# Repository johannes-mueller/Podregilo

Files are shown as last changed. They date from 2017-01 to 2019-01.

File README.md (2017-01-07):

# Podregilo

Arduino based hardware to control a podcasting DAW.

## Disclaimer

By now this project is far from being useful. It might be interesting to other developers though.

# Goal

We are developing and constructing an Arduino based hardware box to control our
DAW while podcasting. The following features are planned:

* mute buttons for all speakers

* buttons to start, stop and prepare the recording

* LED indications of the meter levels of the voices

* buttons to start jingles and other clips

* displaying the current time

# Status

## Prototypes

* First prototype on strip board

  The first prototype was soldered and wired completely manually on stripboards
  using magnet wire for every single comnnection. It was quite a tedious work
  building it but it has the advantage that we could test and develop it
  actually while building the first prototype. In the end the prototype worked
  but turned out to be far to unstable for serious work.

* Second prototype on an etched PCB.

  With what we've learned from the first prototype design, we designed the
  circuit in KiCad and then designed two PCBs, one for the front panel and one
  for the actual circuit. These PCBs we had produced by a professional PCB
  manufacturer. It turned out that we had some bugs in the circuit design which
  we for the second prototype fixed using a grinding tool and again a bit of
  magnet wire.

## Current Status

Right now we have the second prototype up and running and plan to use it in
actual everyday podcasting for a couple of months. Depending on our experiences
we will either have new PCBs produced or we will add some features, that need
hardware modifications.

# Used technology

The hardware is build around an Arduino compatible board, probably the Arduino
nano. We are using parallel shift registers SN74HC165 and SN74HC595 to get and
set the states of our hardware items. On the software side we speak OSC to our
DAW and also probably MIDI to other software. The meter levels we get via
jack. The software is written in python.

# Aimed platform

We are developing on Linux/Ardour. It shouldn't be too difficult to port the
stuff to Mac/Ardour or even Mac/Reaper.

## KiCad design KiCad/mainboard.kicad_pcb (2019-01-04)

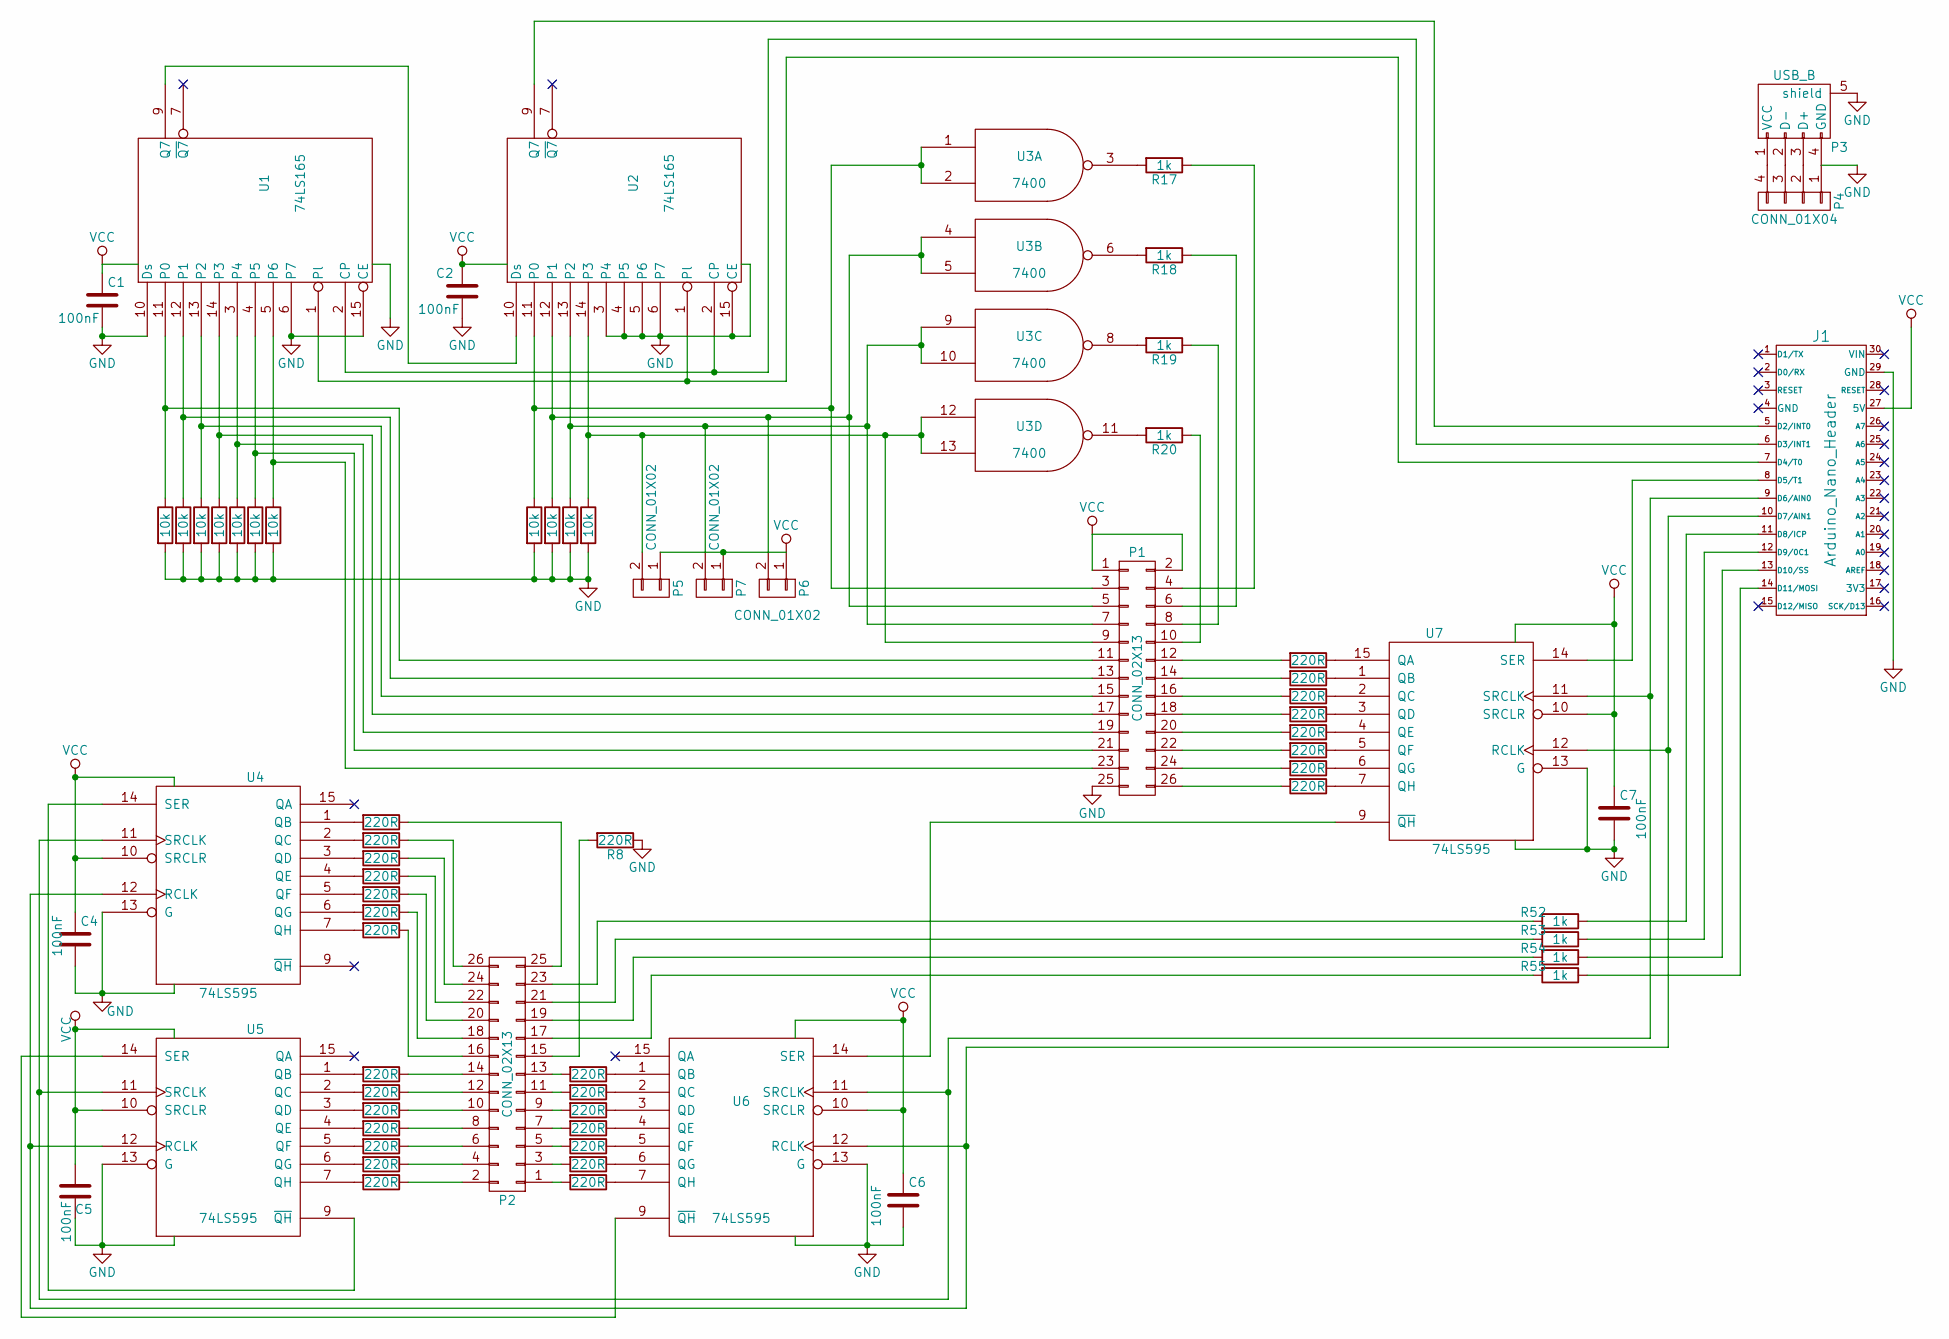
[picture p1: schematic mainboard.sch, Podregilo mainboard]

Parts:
C1, C2, C4, C5, C6, C7: 100nF; C_Disc_D3_P2.5
J1: Arduino_Nano_Header; arduino_nano_header
P1, P2: CONN_02X13; Pin_Header_Straight_2x13
P3: USB_B
P4: CONN_01X04; Pin_Header_Straight_1x04
P5, P6, P7: CONN_01X02; Pin_Header_Straight_1x02
R1, R2, R3, R4, R5, R6, R7, R13, R14, R15, R16: 10k; Resistor_Horizontal_RM7mm
R8, R21, R22, R23, R24, R25, R26, R27, R29, R30, R31, R32, R33, R34, R35, R37, R38, R39, R40, R41, R42, R43, R44, R45, R46, R47, R48, R49, R50, R51: 220R; Resistor_Horizontal_RM7mm
R17, R18, R19, R20, R52, R53, R54, R55: 1k; Resistor_Horizontal_RM7mm
U1, U2: 74LS165; DIP-16_W7.62mm
U3: 7400; DIP-14_W7.62mm
U4, U5, U6, U7: 74LS595; DIP-16_W7.62mm

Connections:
GND: C1.2, C2.2, C4.2, C5.1, C6.2, C7.2, J1.29 (GND), P1.25, P3.4 (GND), P3.5 (shield), P4.1, R1.2, R2.2, R3.2, R4.2, R5.2, R6.2, R7.2, R8.1, R13.2, R14.2, R15.2, R16.2, U1.6 (P7), U1.8 (GND), U1.10 (Ds), U1.15 (CE), U2.3 (P4), U2.4 (P5), U2.5 (P6), U2.6 (P7), U2.8 (GND), U2.15 (CE), U3.7 (GND), U4.8 (GND), U4.13 (G), U5.8 (GND), U5.13 (G), U6.8 (GND), U6.13 (G), U7.8 (GND), U7.13 (G)
unnamed: J1.5 (D2/INT0), U2.9 (Q7)
unnamed: J1.6 (D3/INT1), U1.2 (CP), U2.2 (CP)
unnamed: J1.7 (D4/T0), U1.1 (Pl), U2.1 (Pl)
unnamed: J1.8 (D5/T1), U7.14 (SER)
unnamed: J1.9 (D6/AIN0), U4.11 (SRCLK), U5.11 (SRCLK), U6.11 (SRCLK), U7.11 (SRCLK)
unnamed: J1.10 (D7/AIN1), U4.12 (RCLK), U5.12 (RCLK), U6.12 (RCLK), U7.12 (RCLK)
unnamed: J1.11 (D8/ICP), R52.1
unnamed: J1.12 (D9/0C1), R53.1
unnamed: J1.13 (D10/SS), R54.1
unnamed: J1.14 (D11/MOSI), R55.1
unnamed: P1.3, R13.1, U2.11 (P0), U3.1, U3.2
unnamed: P1.4, R17.1
unnamed: P1.5, P6.2, R14.1, U2.12 (P1), U3.4, U3.5
unnamed: P1.6, R18.1
unnamed: P1.7, P7.2, R15.1, U2.13 (P2), U3.9, U3.10
unnamed: P1.8, R19.1
unnamed: P1.9, P5.2, R16.1, U2.14 (P3), U3.12, U3.13
unnamed: P1.10, R20.1
unnamed: P1.11, R1.1, U1.11 (P0)
unnamed: P1.12, R44.2
unnamed: P1.13, R2.1, U1.12 (P1)
unnamed: P1.14, R45.2
unnamed: P1.15, R3.1, U1.13 (P2)
unnamed: P1.16, R46.2
unnamed: P1.17, R4.1, U1.14 (P3)
unnamed: P1.18, R47.2
unnamed: P1.19, R5.1, U1.3 (P4)
unnamed: P1.20, R48.2
unnamed: P1.21, R6.1, U1.4 (P5)
unnamed: P1.22, R49.2
unnamed: P1.23, R7.1, U1.5 (P6)
unnamed: P1.24, R50.2
unnamed: P1.26, R51.2
unnamed: P2.1, R43.2
unnamed: P2.2, R35.1
unnamed: P2.3, R42.2
unnamed: P2.4, R34.1
unnamed: P2.5, R41.2
unnamed: P2.6, R33.1
unnamed: P2.7, R40.2
unnamed: P2.8, R32.1
unnamed: P2.9, R39.2
unnamed: P2.10, R31.1
unnamed: P2.11, R38.2
unnamed: P2.12, R30.1
unnamed: P2.13, R37.2
unnamed: P2.14, R29.1
unnamed: P2.15, R8.2
unnamed: P2.16, R27.1
unnamed: P2.17, R55.2
unnamed: P2.18, R26.1
unnamed: P2.19, R54.2
unnamed: P2.20, R25.1
unnamed: P2.21, R53.2
unnamed: P2.22, R24.1
unnamed: P2.23, R52.2
unnamed: P2.24, R23.1
unnamed: P2.25, R21.1
unnamed: P2.26, R22.1
unnamed: P3.1 (VCC), P4.4
unnamed: P3.2 (D-), P4.3
unnamed: P3.3 (D+), P4.2
unnamed: R17.2, U3.3
unnamed: R18.2, U3.6
unnamed: R19.2, U3.8
unnamed: R20.2, U3.11
unnamed: R21.2, U4.1 (QB)
unnamed: R22.2, U4.2 (QC)
unnamed: R23.2, U4.3 (QD)
unnamed: R24.2, U4.4 (QE)
unnamed: R25.2, U4.5 (QF)
unnamed: R26.2, U4.6 (QG)
unnamed: R27.2, U4.7 (QH)
unnamed: R29.2, U5.1 (QB)
unnamed: R30.2, U5.2 (QC)
unnamed: R31.2, U5.3 (QD)
unnamed: R32.2, U5.4 (QE)
unnamed: R33.2, U5.5 (QF)
unnamed: R34.2, U5.6 (QG)
unnamed: R35.2, U5.7 (QH)
unnamed: R37.1, U6.1 (QB)
unnamed: R38.1, U6.2 (QC)
unnamed: R39.1, U6.3 (QD)
unnamed: R40.1, U6.4 (QE)
unnamed: R41.1, U6.5 (QF)
unnamed: R42.1, U6.6 (QG)
unnamed: R43.1, U6.7 (QH)
unnamed: R44.1, U7.15 (QA)
unnamed: R45.1, U7.1 (QB)
unnamed: R46.1, U7.2 (QC)
unnamed: R47.1, U7.3 (QD)
unnamed: R48.1, U7.4 (QE)
unnamed: R49.1, U7.5 (QF)
unnamed: R50.1, U7.6 (QG)
unnamed: R51.1, U7.7 (QH)
unnamed: U1.9 (Q7), U2.10 (Ds)
unnamed: U4.14 (SER), U5.9 (~QH)
unnamed: U5.14 (SER), U6.9 (~QH)
unnamed: U6.14 (SER), U7.9 (~QH)
VCC: C1.1, C2.1, C4.1, C5.2, C6.1, C7.1, J1.27 (5V), P1.1, P1.2, P5.1, P6.1, P7.1, U1.16 (VCC), U2.16 (VCC), U3.14 (VCC), U4.10 (SRCLR), U4.16 (VCC), U5.10 (SRCLR), U5.16 (VCC), U6.10 (SRCLR), U6.16 (VCC), U7.10 (SRCLR), U7.16 (VCC)

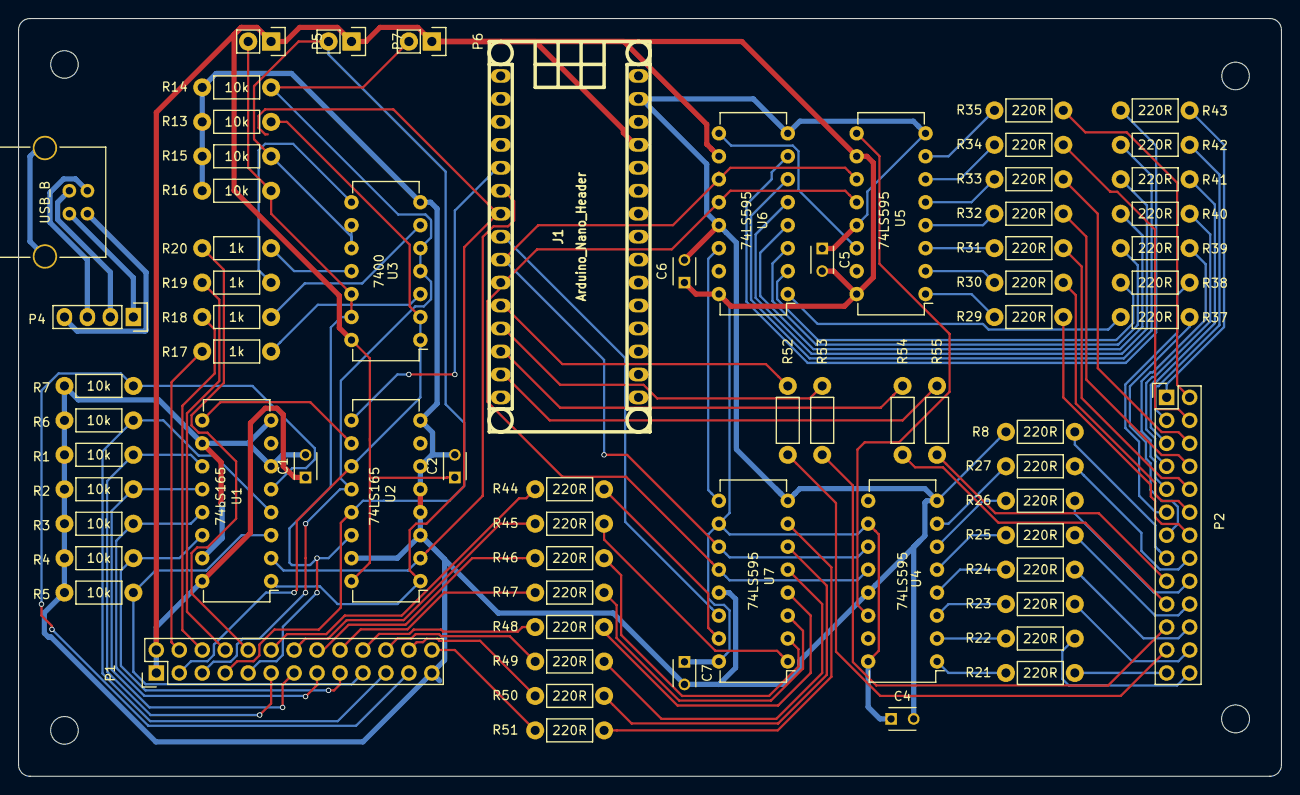
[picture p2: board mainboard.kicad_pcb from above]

Board: 2 copper layers, 139.7 x 83.8 mm, 70 parts (0 on the bottom side), 101 nets.

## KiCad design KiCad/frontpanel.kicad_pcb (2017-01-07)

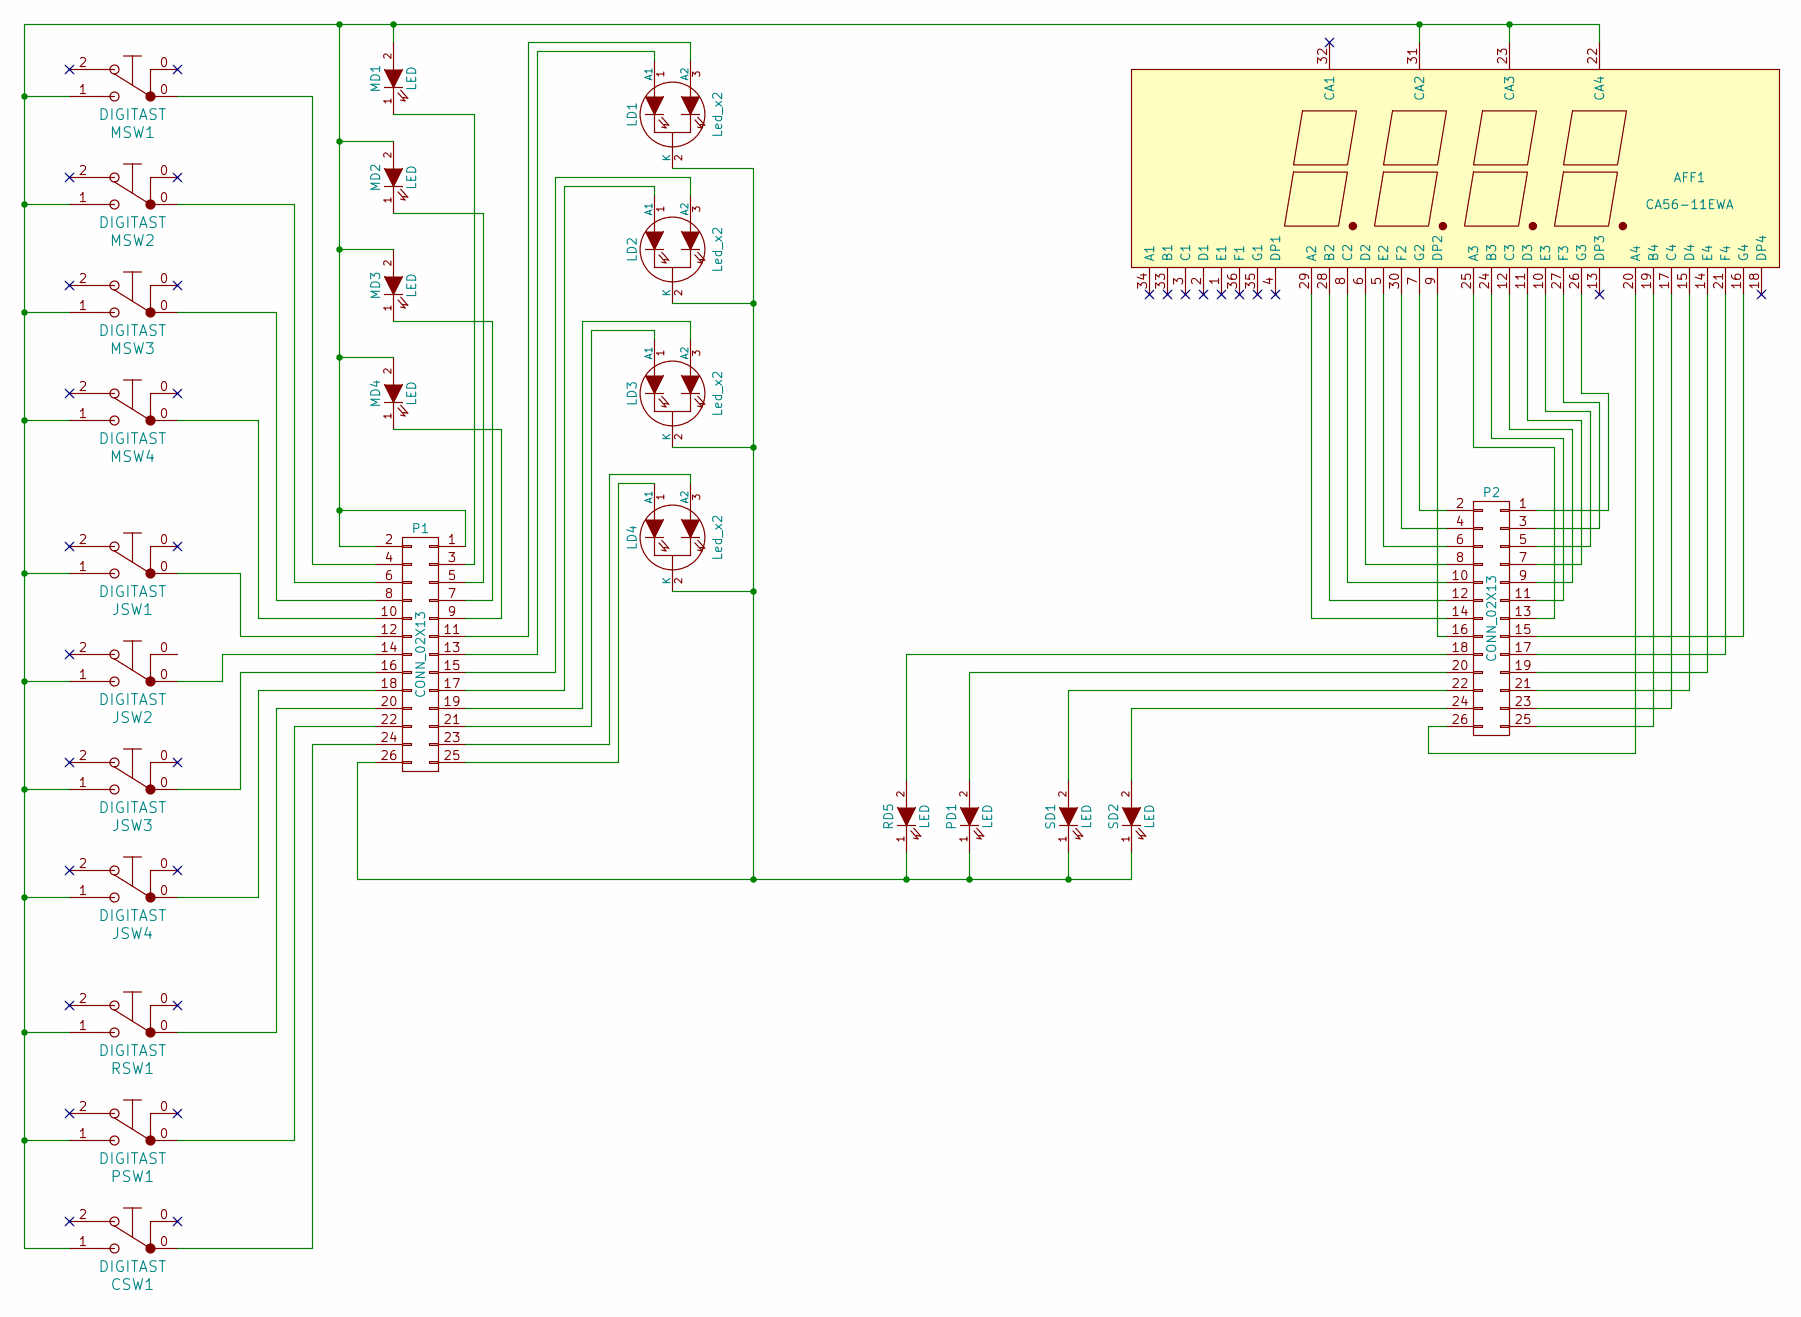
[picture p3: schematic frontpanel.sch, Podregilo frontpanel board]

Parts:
AFF1: CA56-11EWA; Cx56-11
CSW1: DIGITAST; SW-DIGITAST_modified
JSW1, JSW2, JSW3, JSW4: DIGITAST; SW-DIGITAST_modified
LD1, LD2, LD3, LD4: Led_x2; LED-RGB-5MM_Common_Cathode
MD1, MD2, MD3, MD4: LED; LED-3MM
MSW1, MSW2, MSW3, MSW4: DIGITAST; SW-DIGITAST_modified
P1, P2: CONN_02X13; Pin_Header_Straight_2x13
PD1: LED; LED-3MM
PSW1: DIGITAST; SW-DIGITAST_modified
RD5: LED; LED-3MM
RSW1: DIGITAST; SW-DIGITAST_modified
SD1, SD2: LED; LED-5MM

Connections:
unnamed: AFF1.5 (E2), P2.6
unnamed: AFF1.6 (D2), P2.8
unnamed: AFF1.7 (G2), P2.2
unnamed: AFF1.8 (C2), P2.10
unnamed: AFF1.9 (DP2), P2.16
unnamed: AFF1.10 (E3), P2.5
unnamed: AFF1.11 (D3), P2.7
unnamed: AFF1.12 (C3), P2.9
unnamed: AFF1.14 (E4), P2.19
unnamed: AFF1.15 (D4), P2.21
unnamed: AFF1.16 (G4), P2.15
unnamed: AFF1.17 (C4), P2.23
unnamed: AFF1.19 (B4), P2.25
unnamed: AFF1.20 (A4), P2.26
unnamed: AFF1.21 (F4), P2.17
unnamed: AFF1.22 (CA4), AFF1.23 (CA3), AFF1.31 (CA2), CSW1.1, JSW1.1, JSW2.1, JSW3.1, JSW4.1, MD1.2 (A), MD2.2 (A), MD3.2 (A), MD4.2 (A), MSW1.1, MSW2.1, MSW3.1, MSW4.1, P1.1, P1.2, PSW1.1, RSW1.1
unnamed: AFF1.24 (B3), P2.11
unnamed: AFF1.25 (A3), P2.13
unnamed: AFF1.26 (G3), P2.1
unnamed: AFF1.27 (F3), P2.3
unnamed: AFF1.28 (B2), P2.12
unnamed: AFF1.29 (A2), P2.14
unnamed: AFF1.30 (F2), P2.4
unnamed: CSW1.0, P1.24
unnamed: JSW1.0, P1.12
unnamed: JSW2.0, P1.14
unnamed: JSW3.0, P1.16
unnamed: JSW4.0, P1.18
unnamed: LD1.1 (A1), P1.13
unnamed: LD1.2 (K), LD2.2 (K), LD3.2 (K), LD4.2 (K), P1.26, PD1.1 (K), RD5.1 (K), SD1.1 (K), SD2.1 (K)
unnamed: LD1.3 (A2), P1.11
unnamed: LD2.1 (A1), P1.17
unnamed: LD2.3 (A2), P1.15
unnamed: LD3.1 (A1), P1.21
unnamed: LD3.3 (A2), P1.19
unnamed: LD4.1 (A1), P1.25
unnamed: LD4.3 (A2), P1.23
unnamed: MD1.1 (K), P1.3
unnamed: MD2.1 (K), P1.5
unnamed: MD3.1 (K), P1.7
unnamed: MD4.1 (K), P1.9
unnamed: MSW1.0, P1.4
unnamed: MSW2.0, P1.6
unnamed: MSW3.0, P1.8
unnamed: MSW4.0, P1.10
unnamed: P1.20, RSW1.0
unnamed: P1.22, PSW1.0
unnamed: P2.18, RD5.2 (A)
unnamed: P2.20, PD1.2 (A)
unnamed: P2.22, SD1.2 (A)
unnamed: P2.24, SD2.2 (A)

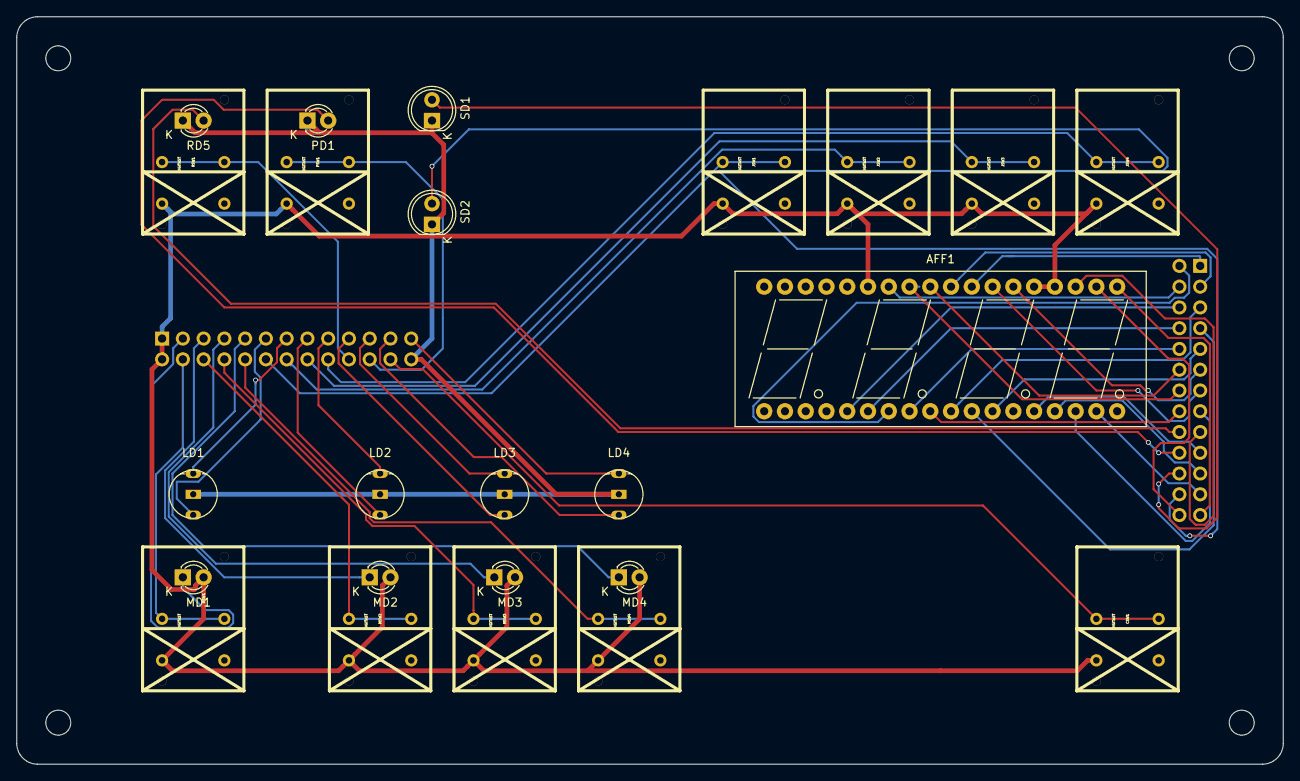
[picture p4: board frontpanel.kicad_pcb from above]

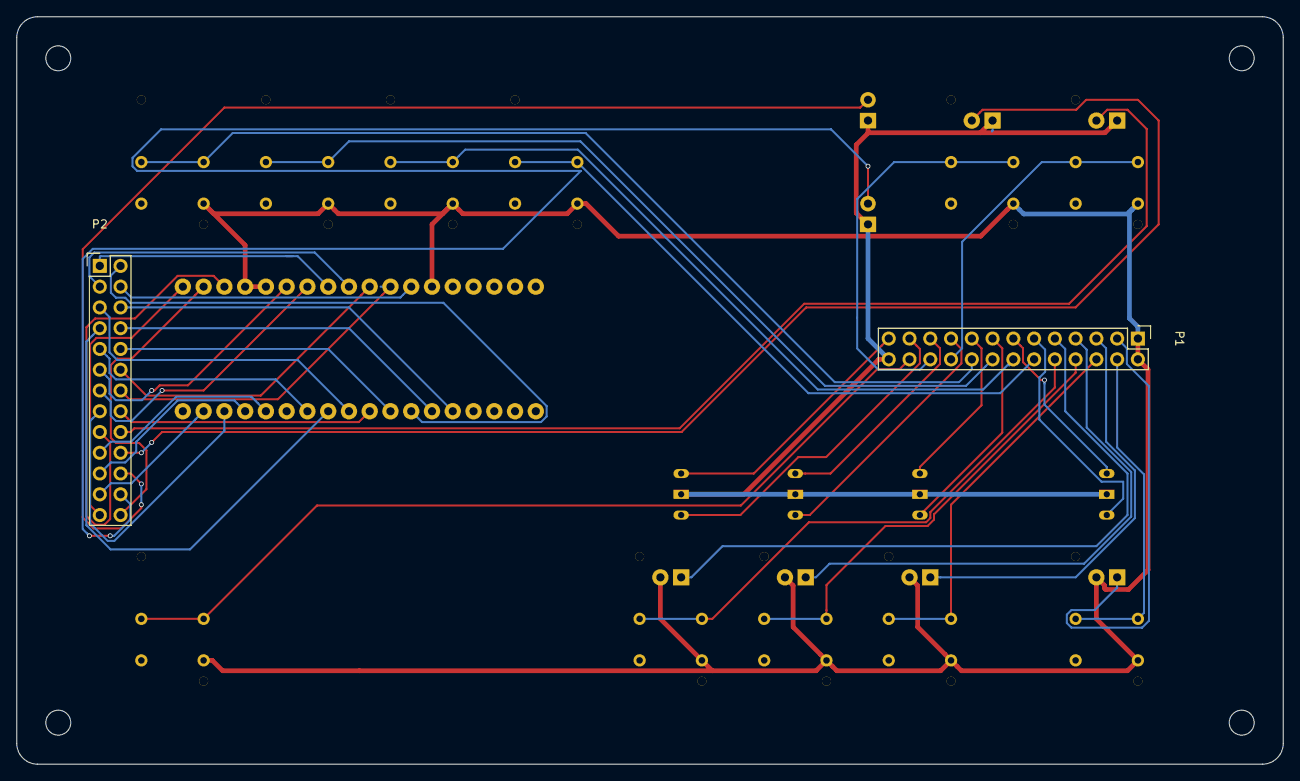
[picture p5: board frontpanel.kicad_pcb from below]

Board: 2 copper layers, 154.9 x 91.4 mm, 26 parts (2 on the bottom side), 51 nets.

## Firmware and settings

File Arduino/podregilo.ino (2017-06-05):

/**
*
* Copyright (c) 2015 Johannes Mueller <github@johannes-mueller.org>
* Distributed under the GNU GPL v2. For full terms see the file /LICENSE.
*
*/

//! Define in/out pins of Arduino
//!
const byte latchPin_in = 4;
const byte dataPin_in = 2;
const byte clockPin_in = 3;

const byte latchPin_out = 7;
const byte dataPin_out = 5;
const byte clockPin_out = 6;

static const unsigned int LONG_PRESS_TIMEOUT = 1000;

//! number of audio channel (podcasting voices)
const byte channelnum = 4;


/** The output buffer.

    We need 4 bytes to shift out. The last one to transport the meter
    levels. The three others transport the time code to the seven
    segment displays.
 */
const byte outbuflen = 4;
byte outbuf[outbuflen];

//! The index of the meter level byte.
const byte levelind = 3;

//! The time of the last level meter update
unsigned long lastMeterUpdate;

//! The DAW timecode in seconds
unsigned int secondsDAW = 0;

//! Is there at the moment or when was the last signal from the DAW
bool haveDAWConnection = false;
unsigned long lastDAWConnectionTime = 0;

double transportSpeed;

bool recEnabled;


unsigned int xruns = 0;


enum LEDcolor { dark = 0b00, red = 0b01, green = 0b10, yellow = 0b11 };
enum LEDstate { off = false, on = true };

struct LED
{
        bool state, oldState;
        unsigned long lastChangeTime;
        unsigned int blinkTime;
        byte pin;
};

struct LED diagRed = { off,off, 0, 0, 9 };
struct LED diagGreen = { off,off, 0, 0, 8 };

struct LED recEnableLED = { off,off, 0, 0, 11 };
struct LED speedLED = { off,off, 0, 0, 10 };


void execLED(struct LED *l)
{
        unsigned long time = millis();

        if (l->blinkTime && (time >  l->lastChangeTime+l->blinkTime))
                l->state = !l->state;

        if (l->state != l->oldState) {
                digitalWrite(l->pin, l->state);
                l->oldState = l->state;
                l->lastChangeTime = time;
        }
}

void setLED(struct LED *l, LEDstate state)
{
        l->state = state;
        l->blinkTime = 0;
}

void blinkLED(struct LED *l, unsigned int period)
{
        l->blinkTime = period;
}

void indicate_xruns()
{
        blinkLED(&diagRed, 2000/xruns);
}


struct Prober
{
        unsigned long probeTime;
        bool answerReceived;
} prober = { 0, false };

const unsigned int probePeriod = 10000;
const unsigned int probeTimeOut = 1000;

void sendProbe()
{
        Serial.write('?');
        prober.answerReceived = false;
        prober.probeTime = millis();
}

bool haveConnection()
{
        static bool optimistic = true;

        if (prober.answerReceived) {
                if (!prober.probeTime| (millis() - prober.probeTime > probePeriod)) {
                        sendProbe();
                        optimistic = true;
                }
                setLED(&diagGreen, on);
                indicate_xruns();
                return true;
        }

        if (millis() > prober.probeTime + probeTimeOut) {
                setLED(&diagGreen, off);
                blinkLED(&diagRed, 200);
                sendProbe();
                optimistic = false;

                return false;
        }

        if (optimistic) {
                setLED(&diagRed, on);
                setLED(&diagGreen, off);
        }

        return false;
}


void passButtonState()
{
	static unsigned int oldData = 0;
	static unsigned int old_long_press = 0;
	static unsigned long press_times[16] = { 0, 0, 0, 0, 0, 0, 0, 0, 0, 0, 0, 0, 0, 0, 0, 0 };

	unsigned int data = 0;
	unsigned int long_press = 0;

	digitalWrite(latchPin_in,LOW);
	delayMicroseconds(1);
	digitalWrite(latchPin_in,HIGH);

	for (unsigned int i=0; i<8*sizeof(data); i++) {
		unsigned int bitval = digitalRead(dataPin_in) << ((8*sizeof(data)-1)-i);
		data |= bitval;

		digitalWrite(clockPin_in,HIGH);
		delayMicroseconds(1);
		digitalWrite(clockPin_in,LOW);
	}

	for (unsigned int i=0; i<8*sizeof(data); i++) {
		unsigned int mask = 1 << i;
		if (data & mask) {
			if (press_times[i]) {
				if (millis() - press_times[i] > LONG_PRESS_TIMEOUT) {
					long_press |= mask;
				}
			} else {
				press_times[i] = millis();
			}
		} else {
			press_times[i] = 0;
		}
	}

	if (data != oldData) {
                Serial.write('b');
		Serial.write((uint8_t*) &data, 2);
		oldData = data;
        }


	unsigned int change = long_press & (long_press ^ old_long_press);
	if (change) {
		Serial.write('l');
		Serial.write((uint8_t*) &change, 2);
	}
	old_long_press = long_press;
}


void adjustLevels()
{
        outbuf[levelind] = 0b00000000;
        char buffer[channelnum];

        byte n = Serial.readBytes(buffer,channelnum);
        if (n!=4)
                outbuf[levelind] = 0b11111111;

        // FIXME: error handling; what if there's not enough bytes available

        for (byte i=0; i<channelnum; i++) {
                byte v = buffer[i];

                if (v>200)
                        outbuf[levelind] |= (red << 2*i);
                else if (v>64)
                        outbuf[levelind] |= (yellow << 2*i);
                else if (v>8)
                        outbuf[levelind] |= (green  << 2*i);
        }

        lastMeterUpdate = millis();
}

union uintBuffer { char buffer[2]; unsigned int s; };

void updateSeconds()
{
        uintBuffer data;
        byte n = Serial.readBytes(data.buffer, 2);
        if (n!=2)
                return;

        secondsDAW = data.s;

        haveDAWConnection = true;
        lastDAWConnectionTime = millis();
}


union doubleBuffer { char buffer[sizeof(double)]; double d; };

void updateSpeed()
{
        doubleBuffer data;
        byte n = Serial.readBytes(data.buffer,sizeof(double));
        if (n!=sizeof(double))
                return;
        // FIXME: error handling

        transportSpeed = data.d;
}

void updateRecEnabled()
{
        char b;
        Serial.readBytes(&b,1);

        recEnabled = (b != '\0');
}

void new_xrun()
{
        xruns += 1;
        indicate_xruns();
}

void reset_xruns()
{
        xruns = 0;
        setLED(&diagRed, off);
}

void checkSerialBuffer()
{
	if (!Serial.available())
		return;

	char c = Serial.read();

        switch(c) {
        case 'l':
                adjustLevels();
                break;
        case 't':
                updateSeconds();
                break;
        case 's':
                updateSpeed();
                break;
        case 'r':
                updateRecEnabled();
                break;
        case 'x':
                new_xrun();
                break;
        case 'X':
                reset_xruns();
                break;
        case '!':
                prober.answerReceived = true;
                break;
        default:
                break;
                // FIXME: error handling
        }
}

void shiftOutData()
{
	for (byte i=0; i<outbuflen; i++) {
		byte p = 1;
		for (byte j=0; j<8; j++) {
			digitalWrite(dataPin_out, p & outbuf[i]);
			p = p << 1;

			digitalWrite(clockPin_out, HIGH);
			delayMicroseconds(1);
			digitalWrite(clockPin_out, LOW);
		}
	}

	digitalWrite(latchPin_out, LOW);
	delayMicroseconds(1);
	digitalWrite(latchPin_out, HIGH);
}


void updateDisplay()
{
        static const byte sevenSegment[] = {
                0b00000001, // 0
                0b01001111, // 1
                0b00010010, // 2
                0b00000110, // 3
                0b01001100, // 4
                0b00100100, // 5
                0b00100000, // 6
                0b00001111, // 7
                0b00000000, // 8
                0b00000100, // 9
        };

        static const byte digit1 = 2;
        static const byte digit2 = 1;
        static const byte digit3 = 0;

        static const byte minus = 0b01111110;

        if (!haveDAWConnection) {
                outbuf[digit1] = minus;
                outbuf[digit2] = minus;
                outbuf[digit3] = minus;

                return;
        }

        unsigned int hours  = secondsDAW / 3600;
        unsigned int minutes = (secondsDAW - hours*3600)/60;

        if (hours > 9)
                outbuf[digit1] = minus;
        else
                outbuf[digit1] = sevenSegment[hours];

        byte tens = minutes/10;
        byte ones = (minutes - tens*10);

        outbuf[digit2] = sevenSegment[tens];
        outbuf[digit3] = sevenSegment[ones];
}

void updateDAWStateLeds()
{
        if (transportSpeed == 0.0)
                setLED(&speedLED, off);
        else
                blinkLED(&speedLED, (unsigned int) 1000.0/transportSpeed);

        setLED(&recEnableLED, LEDstate(recEnabled));
}


void setup()
{
	pinMode(latchPin_in,OUTPUT);
	pinMode(clockPin_in,OUTPUT);
	pinMode(dataPin_in,INPUT);

	pinMode(latchPin_out,OUTPUT);
	pinMode(clockPin_out,OUTPUT);
	pinMode(dataPin_out,OUTPUT);

        pinMode(diagRed.pin, OUTPUT);
        pinMode(diagGreen.pin, OUTPUT);
        pinMode(recEnableLED.pin, OUTPUT);
        pinMode(speedLED.pin, OUTPUT);

        transportSpeed = 0.0;
        recEnabled = false;
        xruns = 0;

        Serial.begin(9600);

        updateDAWStateLeds();

        updateDisplay();
        shiftOutData();
}


void loop()
{
        execLED(&diagRed);
        execLED(&diagGreen);
        execLED(&recEnableLED);
        execLED(&speedLED);

	checkSerialBuffer();

        if (!haveConnection()) {
                setLED(&speedLED, off);
                setLED(&recEnableLED, off);
                return;
        }

        passButtonState();
        updateDisplay();
        updateDAWStateLeds();
	shiftOutData();

        unsigned long time = millis();
        if (time-lastMeterUpdate > 200)
                outbuf[levelind] = 0b00000000;

        if (time-lastDAWConnectionTime > 2000)
                haveDAWConnection = false;
}

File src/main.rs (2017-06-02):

extern crate argparse;
use argparse::{ArgumentParser, List, Store};

extern crate wavefile;
use wavefile::WaveFile;

extern crate itertools;

use std::sync::mpsc::{Sender, Receiver};
use std::sync::mpsc;
use std::sync::{Arc, Mutex, RwLock};

mod arduino;
mod ardour;
mod event;
mod player;
mod cli;
mod jack_client;


fn fill_clips_handle(infiles: Vec<String>, clips_handle: Arc<RwLock<Vec<jack_client::WavData>>>) {
        let mut clips = clips_handle.write().unwrap();

        for (i, filename) in itertools::enumerate(&infiles) {
                println!("Opening file {}: {}", i, filename);
                let wavefile = match WaveFile::open(filename.to_string()) {
                        Ok(w) => w,
                        Err(e) => panic!("{}", e)
                };

                let mut wavdata = vec![];
                for frame in wavefile.iter() {
                        wavdata.push([frame[0] as f32 / 20000., frame[1] as f32 / 20000. ]);
                }
                clips.push(wavdata);
        }
}

fn parse_args(infiles: &mut Vec<String>, port_path: &mut String) {
        let mut ap = ArgumentParser::new();

        ap.set_description("Test soundboard ...");
        ap.refer(port_path).add_argument("USB port", Store, "USB port of arduino device").required();
        ap.refer(infiles).add_argument("input file", List, "WAV file to test").required();
        ap.parse_args_or_exit();
}


fn main() {
        let clips_handle = Arc::new(RwLock::new(vec![]));
        let mut infiles: Vec<String> = vec![];
        let mut port_path = String::new();
        parse_args(&mut infiles, &mut port_path);
        fill_clips_handle(infiles, clips_handle.clone());

        let (event_tx, event_rx) = mpsc::channel::<event::Event>();
        let ev_queue = event::Queue::new(event_tx);

        let (jack_proxy,  jack_thread) = jack_client::Proxy::new(clips_handle.clone(), ev_queue.clone());
        let jp = player::JinglePlayer::new(&jack_proxy);

        let sr = jack_proxy.get_sample_rate();
        let (arduino, arduino_thread) = arduino::Handler::new(&*port_path, ev_queue.clone(), sr);
        let (ardour, ardour_thread) = ardour::Handler::new(ev_queue.clone());
        let cli = cli::Interface::new(ev_queue.clone());

        let mut event_manager = event::Manager::new(event_rx);

        event_manager.register_event_handler(&jp);
        event_manager.register_event_handler(&arduino);
        event_manager.register_event_handler(&cli);
        event_manager.register_event_handler(&ardour);

        arduino.show_recenabled(true);
        while !cli.supposed_to_quit() {
                event_manager.process_next();
        }

        let _ = jack_thread.join();
}

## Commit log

2015-10-24 Initial commit
    Just a little bit to play with. Arduino/podregilo the program to be
    uploaded to Arduino. Python/podregilo is a python program to communicate
    with Arduino and with the DAW.
2015-10-24 Handling mute buttons properly
    Now mute buttons are triggering OSC messages to ardour. The ardour route
    ids (rids) must fit the number of the mute butten. Later we will make
    this configureble by a dict or something like that.
2015-10-25 Make it handle two bytes of button state data
    Using two shift registers we are able to read two bytes of button states
    and pass it via Serial to the python side. In python we split those 16
    bits of button states into 4 groups of 4 buttons. So we have 4 callback
    functions, that we can set, that can handle groups of four buttons.
2015-10-26 Changed shift register pin variable names
    Later on we will have two shift register channels, one for input and one
    for output. So we need to sets of shift register pin variables.
2015-11-01 We use an Arduino nano 328.
2015-11-01 Adjusted pin variable names again.
2015-11-01 We need to wait for the second byte.
    Unfortunately we seem to receive two separate dataReceived events, when
    Arduino sends us two bytes. So we need to wait for the second event, if
    we notice, that we only have one byte.
2015-11-03 Started on drawing the circuit.
2015-11-05 Implemented meter LED states
2015-11-05 Shutdown LEDs when no more devel data is comming
2015-11-06 Simpler documentclass for the circuit design
2015-11-06 Flipped mute and jingle buttons
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2015-11-06 Introduced LED objects.
    LED is a struct, which describes the state of a LED. It comes with
    functions to switch it on or off or make it blink.
2015-11-06 Added diagnosis functionality
    Arduino now is probing the USB bus to check wether our computer app is
    respondig. It sets the diagnosis LEDs accodingly:
    * red: Waiting for response
    * red blink: timeout passed, still probing and hoping
    * green: response received: probing again every 10 seconds
2015-11-07 Some connections on the circuits
2015-11-09 First steps of control button LEDs and time display
2015-11-10 Implemented receiving new time code in Arduino
    ... not tested though. Will test it as soon as the signaling from python
    is ready.
2015-11-10 Some rudimentary tests and fixes in time update
    ... tested only by manual signaling using Serial Monitor.
    [podregilo.ino]
2015-11-12 Make the JackClient not cause latency
    Obviously the JackClient flooded the serial queue because it with evere
    process() call sends something to Arduino. Now we make the Arduino
    connection poll the level data from jack and jack only stores the
    maximum levels since the last poll.
2015-11-12 Send non existing demand for #current_value
    In Ardour this current value query is currently ifd out. So this branch
    is a test, whether it works in principle, given that the feature is
    getting back to Ardour. As soon as the feature is back to Ardour we
    merge this branch into master.
2015-11-13 Implemented debuging channel and use of status LEDs.
2015-11-14 Implemented record prepare button
2015-11-14 Switch off button LEDs when connection is lost.
2015-11-14 Added remove-last-capture to record prepare ...
    ... found that Ardour has the global option of switching off the
    verification dialog of remove last capture.
2016-04-28 Switch to KiCad
    The circuit is documented using KiCad rather than TikZ. This has the
    advantage that we can also develop the PDB inside the project.
    We have two pcbs: the mainboard and the frontpanel board.
    [frontpanel.kicad_pcb, frontpanel.sch, mainboard.kicad_pcb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]
2016-04-28 turned Arduino around
    [mainboard.kicad_pcb]
2016-04-29 some changes and improvments
    [frontpanel.kicad_pcb, mainboard.kicad_pcb, mainboard.sch]
2016-04-30 Flipped the pinpads on the frontpanel board ...
    ... so that we don't have to twist the cables.
    [frontpanel.kicad_pcb, frontpanel.sch]
2016-04-30 Reinforced power wires on frontpanel board
    [frontpanel.kicad_pcb]
2016-04-30 stripped some wires
    [frontpanel.kicad_pcb]
2016-04-30 adjusted frontpanel board size
    [frontpanel.kicad_pcb]
2016-05-01 added some metainfo
    [frontpanel.sch, mainboard.sch]
2016-05-01 adjusted metadata
    [frontpanel.kicad_pcb, mainboard.kicad_pcb]
2017-01-07 corrected origin coordinates
    [frontpanel.kicad_pcb, mainboard.kicad_pcb]
2017-01-07 Ignore Gerber and drill files
2017-01-07 adjust pin numbers to kicad scheme
2017-01-07 fixed wrong led order
    [frontpanel.kicad_pcb, frontpanel.sch]
2017-01-07 added missing connection
    [frontpanel.kicad_pcb]
2017-01-07 Added four missing LED-resistors and ...
    ... turned Arduino again. That was necessary because the connector must not be
    at the edge of the PCB.
    [mainboard.kicad_pcb, mainboard.sch]
2017-01-07 Adjusted pins to KiCad PCB
2017-01-07 Made CLK INH (Pin 15) of the 74HC165s LO
    The input shift registers turned out to have a strong tendency to disturbance
    and their signals were very unstable. The manual of 74HC165 says, that all
    the unused input pins should be either at GND or VCC. For the CLK INH
    (clock inhibit) VCC is not an option, as this would inhibit the clock.
    Therefore we put them to GND.
    It turns out to be far more stable.
    [mainboard.kicad_pcb, mainboard.sch]
2017-01-08 Added decoupling capacitors to the ICs
    [mainboard.sch]
2017-06-02 Adjusted sensitivity of signal leds
2017-06-02 Added capacitors to ICs
    [mainboard.kicad_pcb]
2017-06-02 Created event::Queue, so we no longer need to clone event::Manager
    [main.rs]
2017-06-02 Prototyped registering event observers
2017-06-02 Handover the JoinHandle of the Arduino thread to main()
2017-06-02 Implemented long button presses on for the JinglePlayer
    The state LongPress during Looping is not handled properly.
    Hard to do though :(
2017-06-02 Introduced LevelEvent ...
    ... in order to show audio data on Podregilo's level LEDs.
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2017-06-02 Make sure that we have received the sample rate ...
    ... when we return the jack_client::Proxy instance
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2017-06-05 Use the red LED to indicate xruns.
    The more xruns, the faster we blink
2019-01-04 KiCad update; wiring of denoising capacitors
    [mainboard.kicad_pcb, mainboard.sch]
